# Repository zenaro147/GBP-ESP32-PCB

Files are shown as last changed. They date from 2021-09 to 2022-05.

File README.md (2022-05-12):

# Gameboy Printer Emulator - ESP32 PCB

<a href="https://www.buymeacoffee.com/zenaro147" target="_blank">Buy Me A Coffee</a>

A simple PCB design using EasyEDA to work with this projects by me:
* [NeoGB Printer](https://github.com/zenaro147/NeoGB-Printer)
* [WiFi GBP Emulator - ESP32 Version](https://github.com/zenaro147/wifi-gbp-emulator/tree/feature/v3-esp32)



## BOM list 
| Component | Where to buy |
| --- | --- |
| ESP32 Dev Board (38 pins) | [AliExpress](https://a.aliexpress.com/_mKXR5OW) |
| OLED Display 128x32 (0.91 inch) (optional) | [AliExpress](https://a.aliexpress.com/_mOHbftG) |
| SD Card/MicroSD Card Module (Choose only one! I recommend the Standard SD module) | [AliExpress - SD Card](https://a.aliexpress.com/_mMWz2km) / [AliExpress - MicroSD](https://a.aliexpress.com/_m0SS4P4) |
| 4 channel Logical Level Shifter (highly recommended) | [AliExpress](https://a.aliexpress.com/_m07pFpU) |
| Female Pin Header with 40 pins (you need at least 38 pins, or 2 with 20pins) | [AliExpress](https://www.aliexpress.com/item/4000096276148.html) |
| PushButton 4.5x4.5mm (any height) - ONLY REV. 1  | [AliExpress](https://www.aliexpress.com/item/1005001629344310.html) |
| PushButton 6x6mm (any height) - ONLY REV. 2 (still W.I.P.) | [AliExpress](https://www.aliexpress.com/item/1005003251295065.html) |
| 5k or 10k resistor | [AliExpress](https://www.aliexpress.com/item/4001082088353.html) |
| MicroUSB Female (optional, but mandatory if you want the charging module)| [AliExpress](https://www.aliexpress.com/item/4000385426649.html) |
| Charging Module with StepUp (5V) - DD05CVSA (optional) | [AliExpress](https://www.aliexpress.com/item/33034500618.html) |
| Micro Switch - SS-12D00G3 (optional, but mandatory if you want the charging module) | [AliExpress](https://www.aliexpress.com/item/1005003938856402.html) |
| 1500mah Li-Po Battery (optional, but mandatory if you want the charging module) | [AliExpress](https://www.aliexpress.com/item/1005003235425542.html) |
| AGB Link Port Connector (optional) | [AliExpress](https://www.aliexpress.com/item/32858521427.html) |
| RGB LED 5mm (optional) | [AliExpress](https://www.aliexpress.com/item/1005002535018824.html) |
| 220R resistor (if you want the LED) | [AliExpress](https://www.aliexpress.com/item/4001082088353.html) |

## How to build
* First of all, solder the resistors, RGB led, button, the level shifter, USB port, and the female pin bar (oh, and the AGB link port, if you have one)
* Put a little bit of in the RGB led jumper to bridge the middle pad to one of the other pads. (If you want a passthrough USB power, make bridge pads too)
* Cut all remaining legs
* Solder the SD/Micro SD module
* Cut all remaining legs
* Solder the male pin head for the charging module (but don't solder the module yet)
* Cut all remaining legs
* Solder the display and the battery
* Cut all remaining legs
* Solder the charging module into the pins

I highly recommend to add some tape to prevent any unwanted contact between the modules (on SD/MicroSD, charging module and display to be more specific) and the solder points

## Inspirations/References
* [Game Boy -related custom hardware by gekkio](https://github.com/Gekkio/gb-hardware)
* [Game Boy WiFi Printer - D1 Mini Shield](https://github.com/cristofercruz/gbp-esp-shield-pcb)
* [Gameboy Link Cable Breakout PCB](https://github.com/Palmr/gb-link-cable)

## External References
* [ESP32-DEVKITC-32D](https://www.snapeda.com/parts/ESP32-DEVKITC-32D/Espressif%20Systems/view-part/)
* [ESP32 Pinout](https://4.bp.blogspot.com/-nGLtB2nUrDg/Wp6DQbzcJMI/AAAAAAAABq0/A6Z46p0SQSEdERWocWL94oUmeATMQre4wCLcBGAs/s1600/3.png)
* [ESP32 dev kit power options](https://techexplorations.com/guides/esp32/begin/power/)
* [Power Supply for ESP32 with Battery Charger & Boost Converter](https://how2electronics.com/power-supply-for-esp32-with-boost-converter-battery-charger/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)
* [ESP32 – Getting Battery charging level](https://www.pangodream.es/esp32-getting-battery-charging-level)

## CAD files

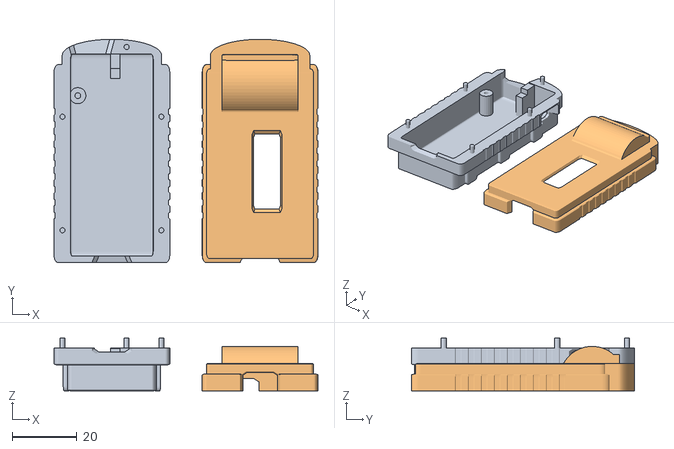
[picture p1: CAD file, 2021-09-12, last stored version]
GBP Case/wifi-printer.obj
81.4 x 68.9 x 16.3

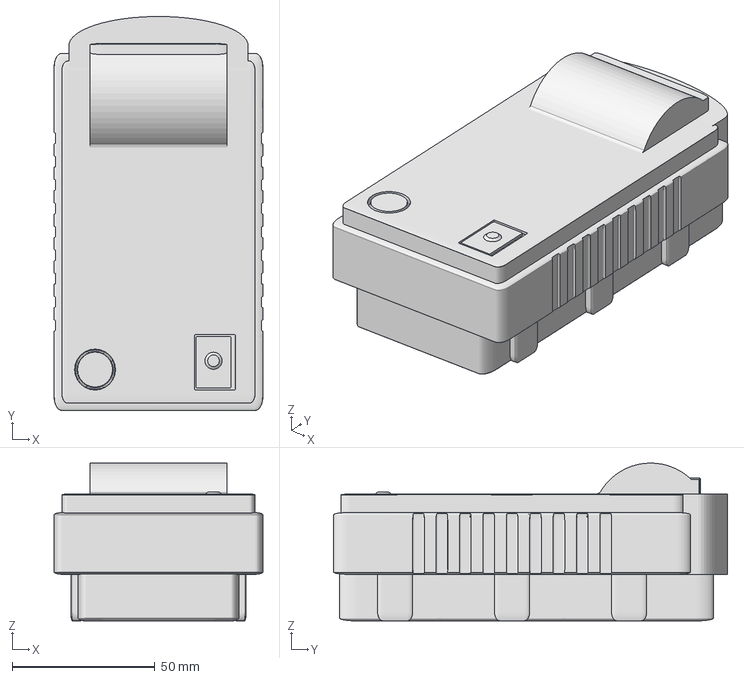
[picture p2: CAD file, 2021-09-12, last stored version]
GBP Case/Solid_GBP.3mf
73.1 x 138.0 x 55.3 mm

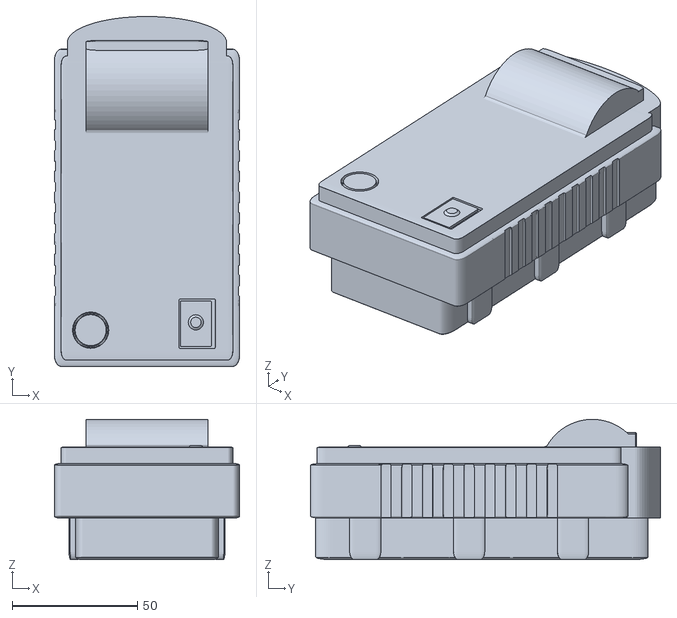
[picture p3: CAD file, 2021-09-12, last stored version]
GBP Case/Solid_GBP.bkp.stl
74.2 x 140.0 x 56.1

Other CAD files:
PCB Design/tools/kicad-footprints-5.1.7/Sources/Inductor_SMD/L_Coilcraft_LPS5030.FCStd
PCB Design/tools/kicad-footprints-5.1.7/Sources/Package_LGA/Infineon_PG-LLGA-5-1.FCStd
PCB Design/tools/kicad-footprints-5.1.7/Sources/Package_SON/X2SON-4_1x1mm_P0.65mm.fcstd
PCB Design/tools/kicad-footprints-5.1.7/Sources/Package_TO_SOT_THT/sod-70_P5.08mm.fcstd
PCB Design/tools/kicad-footprints-5.1.7/Sources/Inductor_SMD/L_Wuerth_WE-TPC-3816.FCStd
PCB Design/tools/kicad-footprints-5.1.7/Sources/Package_TO_SOT_THT/sod-70.fcstd
PCB Design/tools/gekkio-kicad-libs-master/openscad/utils.scad

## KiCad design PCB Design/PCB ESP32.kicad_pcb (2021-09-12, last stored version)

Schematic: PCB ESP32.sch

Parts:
D1: StatusLED; LED_D5.0mm
D2: PowerLED; LED_D5.0mm
J3: GameBoy_LinkPort; GameBoy_LinkPort_MGB_Horizontal
J4: 5vBatteryPins; PinHeader_1x02_P2.54mm_Horizontal
J5: HV_pins; PinSocket_1x06_P2.54mm_Vertical
J6: LV_pins; PinSocket_1x06_P2.54mm_Vertical
R1, R2: 1k Resistor; R_Axial_DIN0207_L6.3mm_D2.5mm_P10.16mm_Horizontal
R3, R4: 10k Resistor; R_Axial_DIN0207_L6.3mm_D2.5mm_P10.16mm_Horizontal
R5: 4.7k Resistor; R_Axial_DIN0207_L6.3mm_D2.5mm_P10.16mm_Horizontal
SW1: SW_Push; SW_Tactile_Straight_KSA0Axx1LFTR
U1: ESP32_DEVBOARD_WROOM; MODULE_ESP32-DEVKITC-32D
U2: SD_Card_module; PinHeader_1x08_P2.54mm_Vertical
U3: OledDisplay_SSD1305_128_32; PinHeader_1x04_P2.54mm_Vertical
U4: MicroSD_Card_module; PinHeader_1x06_P2.54mm_Vertical

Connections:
GND: D1.1 (K), D2.1 (K), J3.6 (GND), J3.SH, J4.1, J5.4, J6.4, R3.1, R4.2, U1.14, U1.20, U1.26, U2.1, U2.8, U3.4, U4.6
unnamed: D1.2 (A), R1.1
unnamed: D2.2 (A), R2.1
unnamed: J3.1 (VDD), R5.1
unnamed: J3.2 (SO), J5.6
unnamed: J3.3 (SI), J5.5
unnamed: J3.5 (SC), J5.2
unnamed: J4.2, J5.3, R2.2, U1.19, U2.6, U3.3, U4.5
unnamed: J6.2, U1.28
unnamed: J6.3, SW1.2, U1.1
unnamed: J6.5, U1.21
unnamed: J6.6, U1.27
unnamed: R1.2, U1.32
unnamed: R3.2, SW1.1, U1.5
unnamed: R4.1, R5.2, U1.7
unnamed: U1.10, U2.2, U4.4
unnamed: U1.12, U2.3, U4.2
unnamed: U1.15, U2.4, U4.3
unnamed: U1.22, U1.30, U3.2
unnamed: U1.25, U1.31, U3.1
unnamed: U1.35, U2.5, U4.1

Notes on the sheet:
GB Printer Emulator - ESP32 Version
Works to these projects: Wifi GBP Emulator - ESP32 Version (https://bit.ly/3mIIKRQ) BitBoy Clone (https://bit.ly/3zsWsfd)

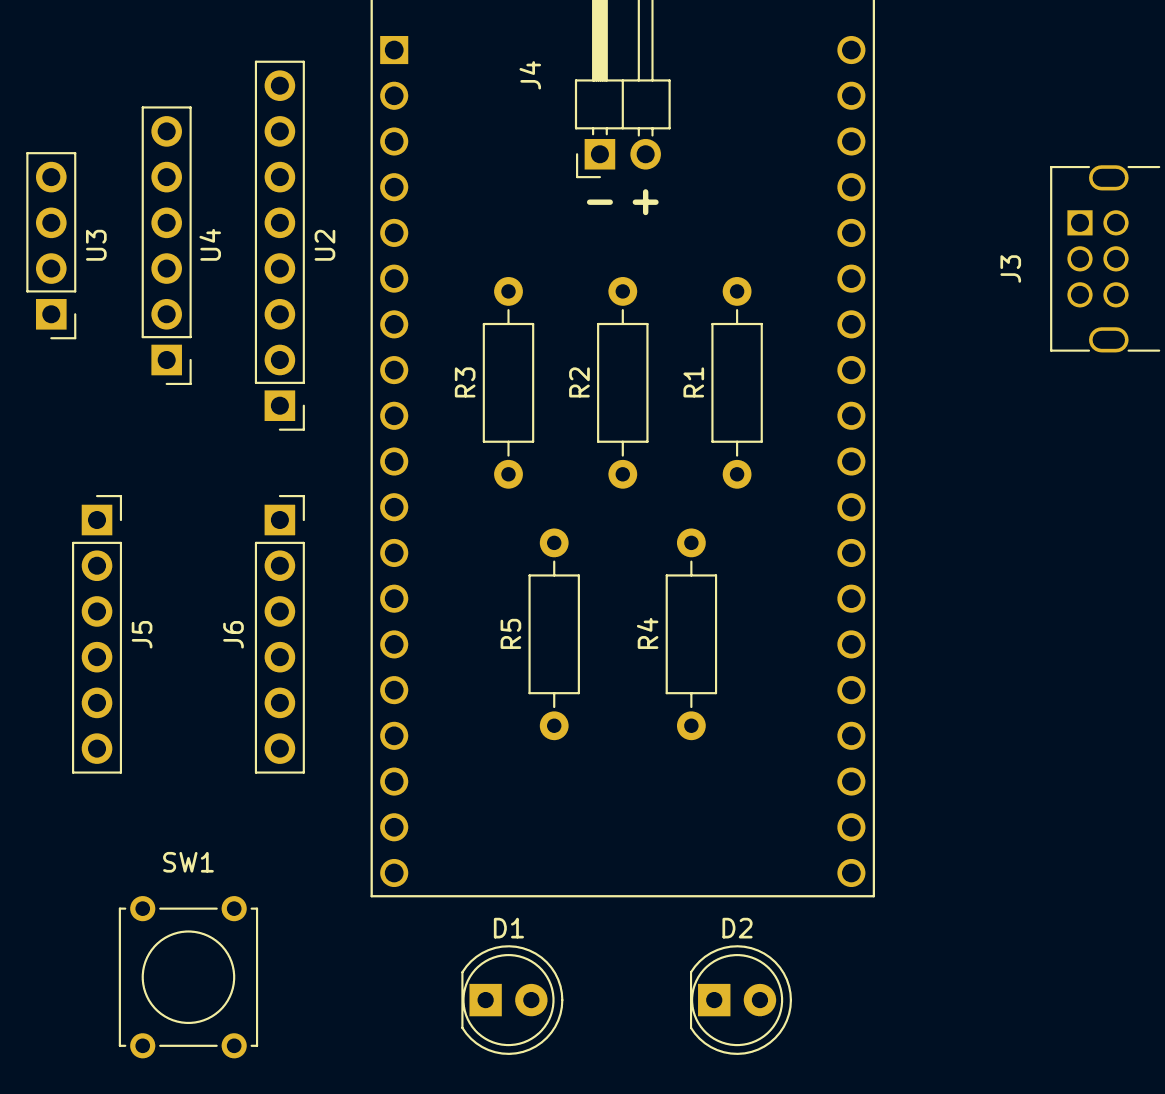
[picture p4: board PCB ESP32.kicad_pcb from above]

Board: 2 copper layers, 16 parts (0 on the bottom side), 21 nets, no tracks yet.

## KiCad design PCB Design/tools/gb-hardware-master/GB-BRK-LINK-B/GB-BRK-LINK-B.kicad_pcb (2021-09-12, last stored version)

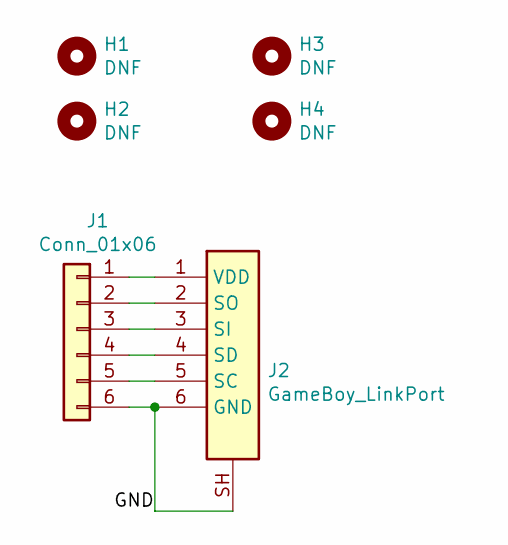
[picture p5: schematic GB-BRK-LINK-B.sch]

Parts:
H1, H2, H3, H4: DNF; MountingHole_3.2mm_M3
J1: Conn_01x06; PinHeader_1x06_P2.54mm_Vertical
J2: GameBoy_LinkPort; GameBoy_LinkPort_MGB_Horizontal

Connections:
/GND: J1.6, J2.6 (GND), J2.SH
unnamed: J1.1, J2.1 (VDD)
unnamed: J1.2, J2.2 (SO)
unnamed: J1.3, J2.3 (SI)
unnamed: J1.4, J2.4 (SD)
unnamed: J1.5, J2.5 (SC)

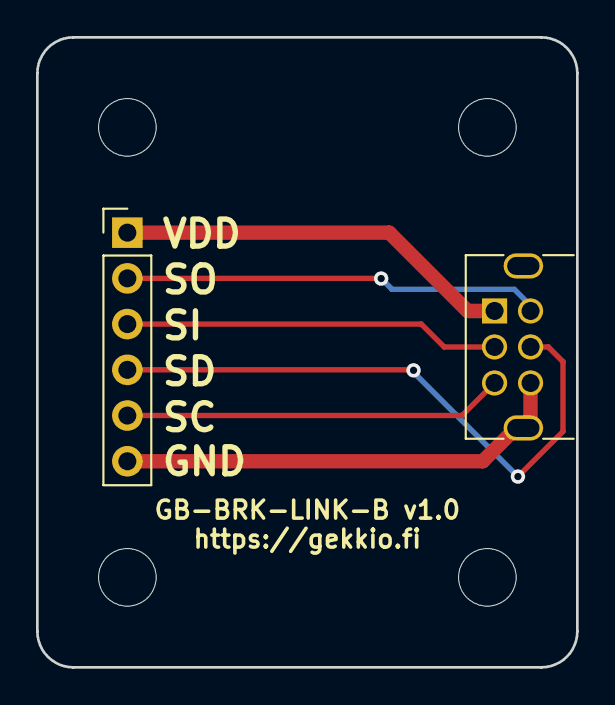
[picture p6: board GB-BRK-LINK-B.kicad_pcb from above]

Board: 2 copper layers, 30.0 x 35.0 mm, 6 parts (0 on the bottom side), 6 nets.

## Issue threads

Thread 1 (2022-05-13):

ToDo list for the Rev2

zenaro147, 2022-05-13:
* One side mount
*bigger push button (maybe 6mm and a recommended height, since these buttons have a lot of height variants)
* make the code as default for the PCB build
* add abount the ESP boot button in the WIKI

Raphael-Boichot, 2022-05-14:
Put all the connections on the same side if possible (USB and serials.). It is more aesthetic.

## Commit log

2021-09-12 Added 3d model case
    [Solid_GBP.3mf, Solid_GBP.bkp.stl, wifi-printer.obj]
2022-03-15 Change to EasyEDA
    [GB-BRK-LINK-B-B_Cu.gbr, GB-BRK-LINK-B-B_Mask.gbr, GB-BRK-LINK-B-B_Paste.gbr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]
2022-03-15 Remove Files
    [Solid_GBP.3mf, Solid_GBP.bkp.stl, wifi-printer.obj]
2022-03-16 Update Files
    [NeoGBP_Design_PCB.pcbdoc, NeoGBP_Design_Schema.schdoc]
2022-03-16 Added Copper Area to GND
2022-04-20 Board Review after first build
